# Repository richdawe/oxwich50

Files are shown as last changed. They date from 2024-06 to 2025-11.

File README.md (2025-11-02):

# Oxwich50

The Oxwich50 keyboard is a 40-50% keyboard that can be mounted in a 60% traymount case, using the GH60 mounting points.

It was inspired by the many unibody split keyboards that I saw in the [Keyboard Builders Digest newsletter](https://kbd.news/). A lot of those keyboards had 30-36 keys, which seemed like too few for me. I wondered what a 60% keyboard would be like if you removed some keys, added an arrow cluster, and split the halves a bit, for a _potentially_ more comfortable typing position.

The PCB and plate were designed and made for me by [Mechboards Ltd](https://mechboards.co.uk/) in the UK.

Please see also my [keymap](https://github.com/richdawe/qmk_firmware/blob/master/keyboards/oxwich50/keymaps/richdawe/keymap.c) and the [QMK support](https://github.com/richdawe/qmk_firmware/tree/master/keyboards/oxwich50), both in my fork of the QMK firmware.

The keyboard is named after [Oxwich](https://en.wikipedia.org/wiki/Oxwich), which is a village on the Gower, near Swansea in Wales, UK.

# TODOs

 - [ ] Licence for h/w
 - [ ] Add photos
 - [ ] List of limitations with v1
   - [ ] plate hole in wrong place, stab screw conflict with 60% case post, maybe unnecessary holes? in the plate for 60% cases I use
   - [ ] also need to clip one of the plastic legs on a switch going in the RHS enter position - this is on the RHS, row above bottom one; was this with 5-pin switches?
   - [ ] holes for stabs are quite tight, could make them wider - also would they fit more stabs if they were taller?
 - [ ] Make the PCB compatible with o-ring mounting in a Bakeneko60 case
 - [ ] Other improvements? E.g.: Expose Pico debug connector for debugging QMK with the Rasbperry Pi debug peripheral?

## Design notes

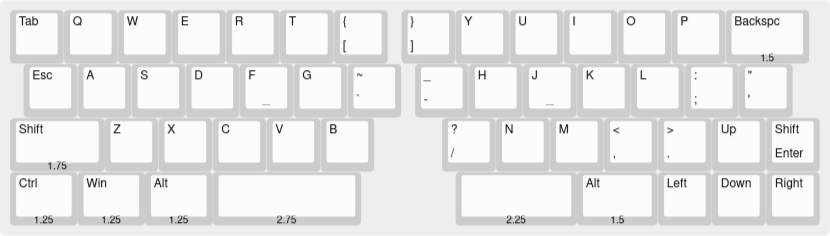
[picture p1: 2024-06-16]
oxwich50-kle.png

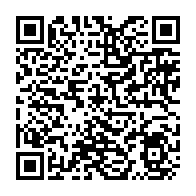
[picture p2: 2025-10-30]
qr/oxwich50-keymap-qr.png

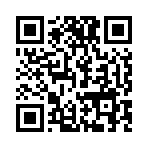
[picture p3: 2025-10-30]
qr/oxwich50-source-qr.png

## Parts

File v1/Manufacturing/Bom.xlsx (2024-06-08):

Designator | Footprint | Quantity | Value | JLCPCB Part #
SW43,SW42,SW44,SW46,SW29,SW14,SW47,SW45,SW28,SW4,SW18,SW21,SW40,SW6,SW10,SW39,SW36,SW13,SW15,SW25,SW26,SW32,SW20,SW33,SW49,SW1,SW12,SW16,SW22,SW27,SW19,SW11,SW48,SW5,SW30,SW50,SW17,SW41,SW3,SW24,SW38,SW35,SW34,SW2,SW37,SW31,SW8,SW7,SW23,SW9 | SW_Hotswap_Kailh_MX_1.00u | 50 | SW_Push_45deg | CPG151101S11
DS1 | D_SOD-123 | 1 | DSK34 SOD-123 | C41029
D7,D26,D49,D33,D17,D38,D2,D29,D31,D41,D40,D36,D11,D13,D39,D35,D24,D4,D43,D37,D45,D19,D1,D30,D48,D28,D10,D15,D32,D14,D20,D23,D18,D5,D22,D34,D8,D6,D50,D9,D16,D46,D12,D3,D21,D27,D47,D25,D44,D42 | D_SOD-123 | 50 | 1N4148W | C81598
U2 | SOIC-8_5.23x5.23mm_P1.27mm | 1 | W25Q128JVS | C97521
C14,C15,C4,C7 | C_0402_1005Metric | 4 | 1u | C52923
U3 | SOT-23-5 | 1 | TLV70030DDCR | C36463
R8,R9 | R_0402_1005Metric | 2 | 5K1 | C25905
R3,R7 | R_0402_1005Metric | 2 | 1K | C11702
C11,C9,C5,C6,C10,C12,C8,C13 | C_0402_1005Metric | 8 | 100n | C1525
U1 | QFN-56-1EP_7x7mm_P0.4mm_EP3.2x3.2mm | 1 | RP2040 | C2040
R5,R4 | R_0402_1005Metric | 2 | 27R4 | C284479
R2 | R_0402_1005Metric | 1 | 200R | C25087
RST1 | SW_SPST_TL3342 | 1 | SW_SPST_TL3342 | C2886897
C2,C3 | C_0402_1005Metric | 2 | 27pF | C86287
F1 | R_0805_2012Metric_Pad1.20x1.40mm_HandSolder | 1 | Fuse | C883108
Y1 | Crystal_SMD_2520-4Pin_2.5x2.0mm | 1 | 12Mhz, 10pf, 10ppm | C284154
C1 | C_0402_1005Metric | 1 | 2u2 | C12530
J1 | USB_C_Receptacle_HRO_TYPE-C-31-M-12 | 1 | USB_C_Receptacle_USB2.0 | C165948
R6 | R_0402_1005Metric | 1 | 10K | C25744
R1 | R_0402_1005Metric | 1 | 1R | C881121
U4 | Diodes_UDFN-10_1.0x2.5mm_P0.5mm | 1 | D3V3XA4B10LP | C1980462

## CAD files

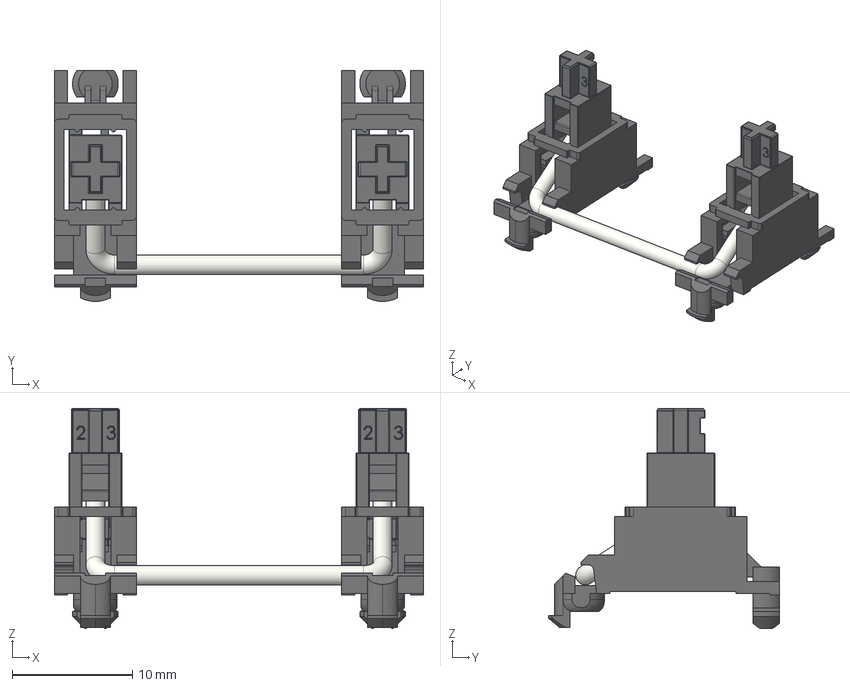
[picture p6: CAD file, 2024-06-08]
v1/kiswitch/source_3d/Mounting_Keyboard_Stabilizer/Stabilizer_Cherry_MX_2u.FCStd
30.7 x 19.2 x 18.3 mm
Bar
Stabilizer_Key_
Stabilizer_Base_
Stabilizer_Key
Stabilizer_Base

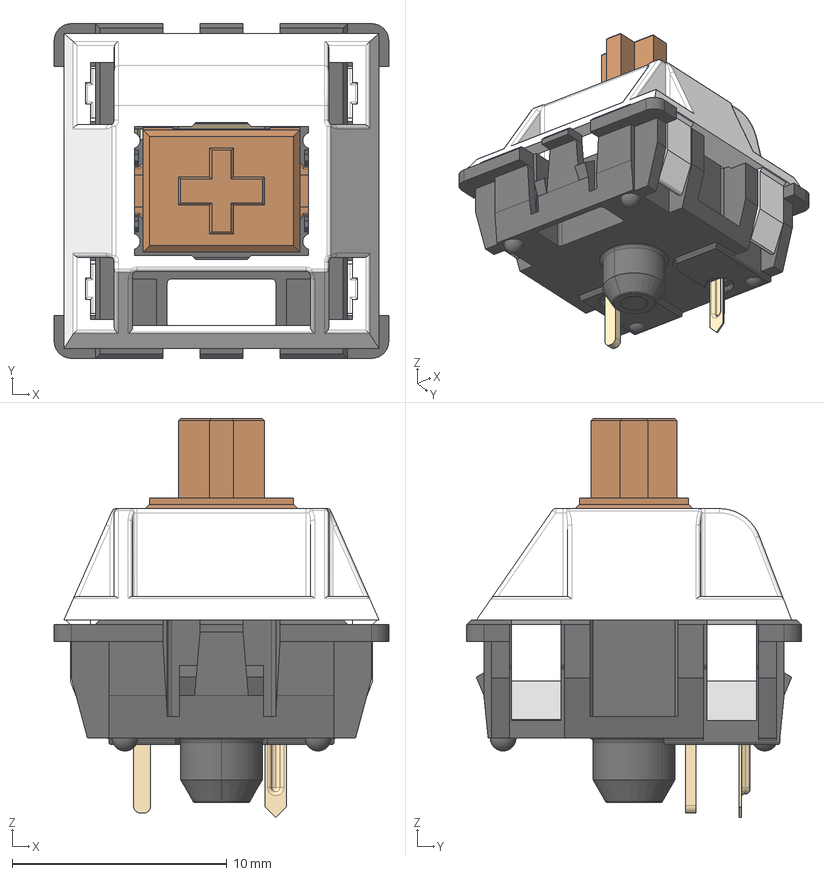
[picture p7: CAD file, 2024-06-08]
v1/kiswitch/source_3d/Switch_Keyboard_Cherry_MX/SW_Cherry_MX_Plate.FCStd
15.6 x 15.6 x 18.6 mm
Lower_Housing
Upper_Housing
Stem
Pin_1
Pin_2
Spring
Clicker

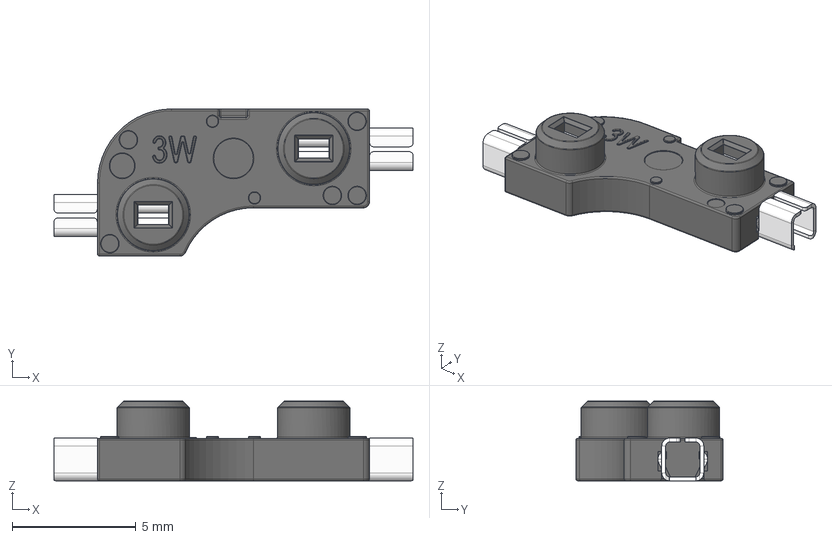
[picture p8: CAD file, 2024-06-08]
v1/kiswitch/source_3d/Switch_Keyboard_Kailh/SW_Hotswap_Kailh.FCStd
14.5 x 5.95 x 3.22 mm
Pin_1
Pin_2
Plastic

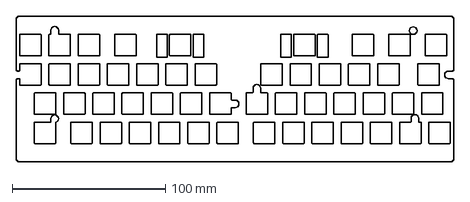
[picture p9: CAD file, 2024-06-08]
v1/Manufacturing/plate.dxf
285.3 x 94.8 mm

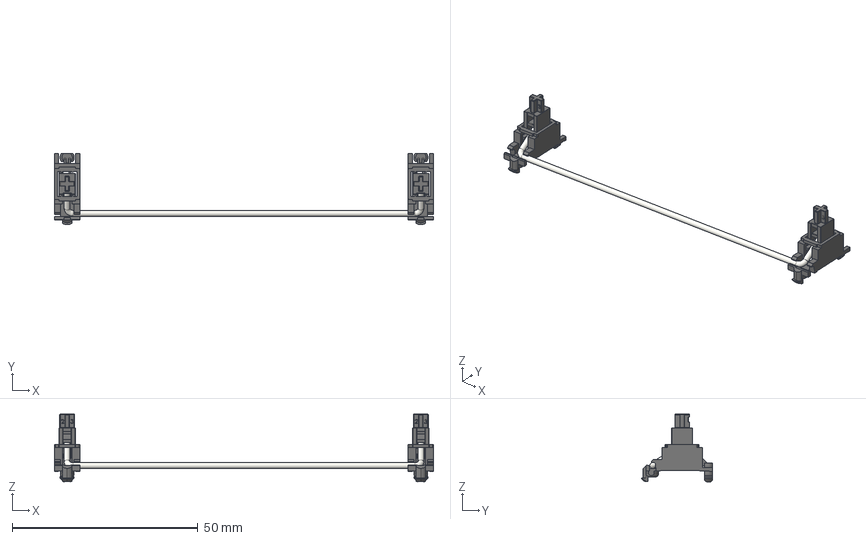
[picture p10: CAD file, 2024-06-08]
v1/kiswitch/source_3d/Mounting_Keyboard_Stabilizer/Stabilizer_Cherry_MX_6u.FCStd
102.1 x 19.2 x 18.3 mm
Bar
Stabilizer_Key_
Stabilizer_Base_
Stabilizer_Key
Stabilizer_Base

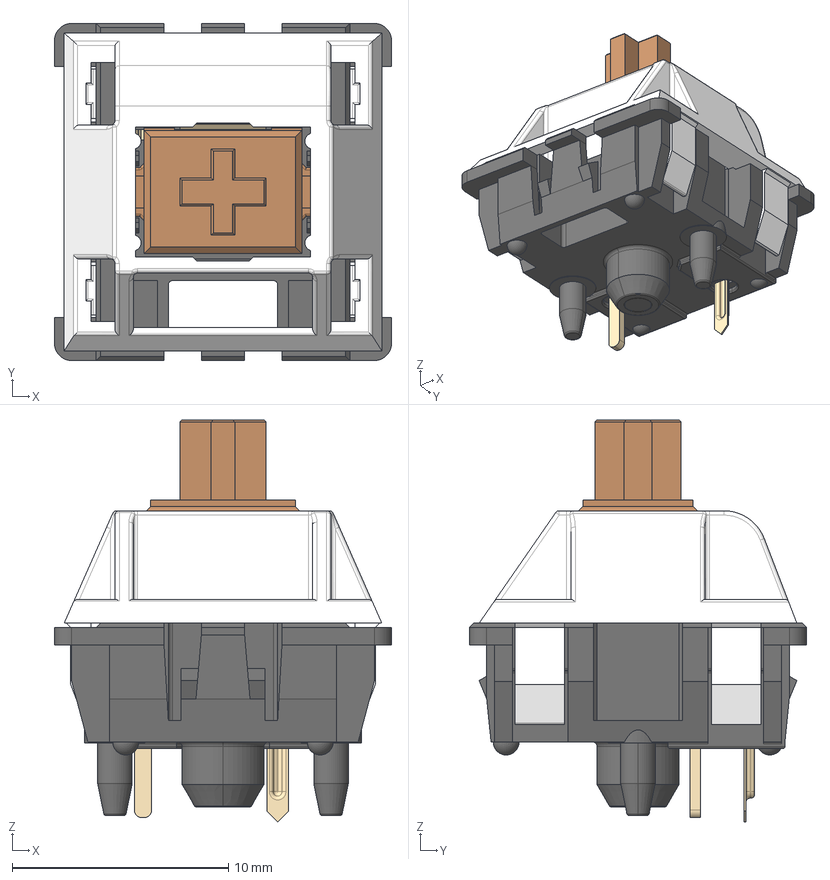
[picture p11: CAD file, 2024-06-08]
v1/kiswitch/source_3d/Switch_Keyboard_Cherry_MX/SW_Cherry_MX_PCB.FCStd
15.6 x 15.6 x 18.6 mm
Lower_Housing
Upper_Housing
Stem
Pin_1
Pin_2
Spring
Clicker

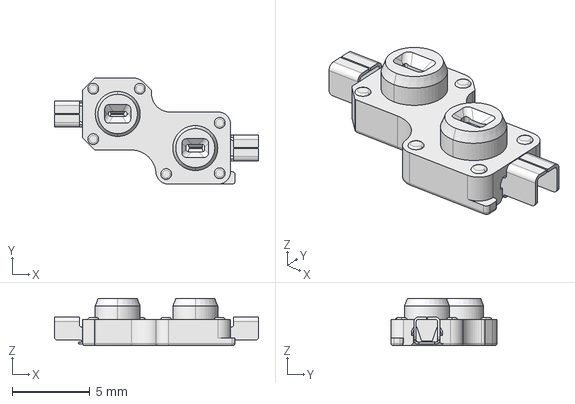
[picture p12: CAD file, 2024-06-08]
v1/kiswitch/source_3d/Switch_Keyboard_Kailh/SW_Hotswap_Kailh_Choc_v1.FCStd
13.2 x 6.85 x 3.05 mm

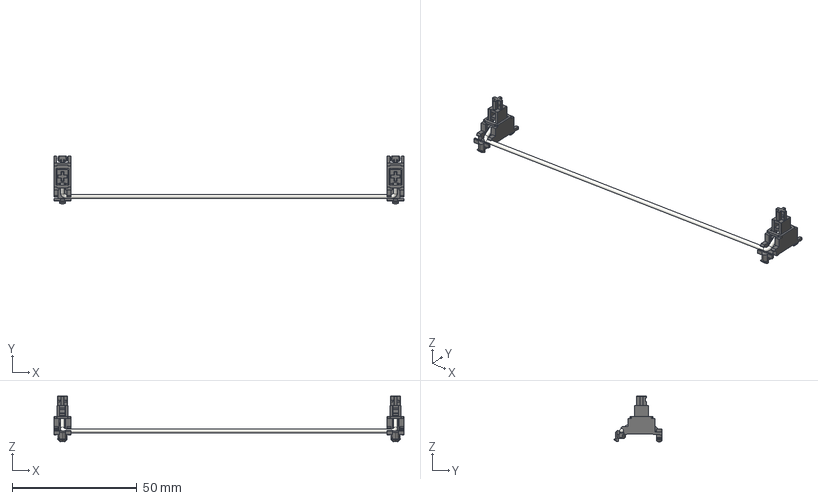
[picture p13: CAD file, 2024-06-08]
v1/kiswitch/source_3d/Mounting_Keyboard_Stabilizer/Stabilizer_Cherry_MX_8u.FCStd
140.1 x 19.2 x 18.3 mm
Bar
Stabilizer_Key_
Stabilizer_Base_
Stabilizer_Key
Stabilizer_Base

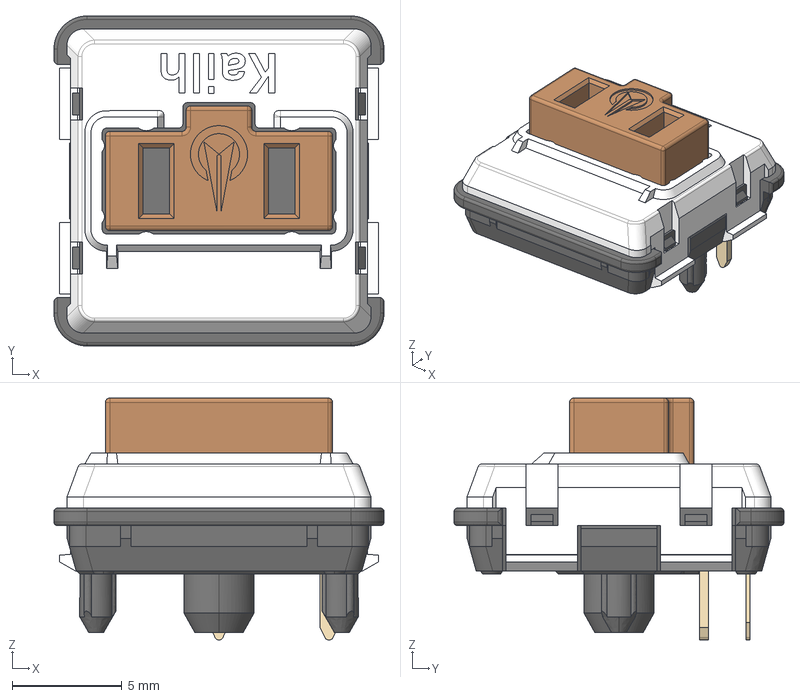
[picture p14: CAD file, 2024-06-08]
v1/kiswitch/source_3d/Switch_Keyboard_Kailh/SW_Kailh_Choc_V1.FCStd
15.0 x 15.0 x 11.0 mm
Upper_Housing
Lower_Housing
Stem
Pin_2
Pin_1

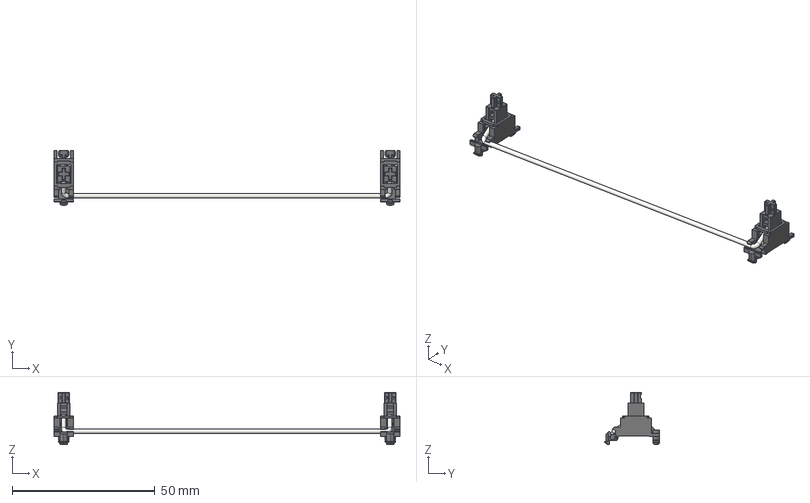
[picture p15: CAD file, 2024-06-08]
v1/kiswitch/source_3d/Mounting_Keyboard_Stabilizer/Stabilizer_Cherry_MX_7u.FCStd
121.1 x 19.2 x 18.3 mm
Bar
Stabilizer_Key_
Stabilizer_Base_
Stabilizer_Key
Stabilizer_Base

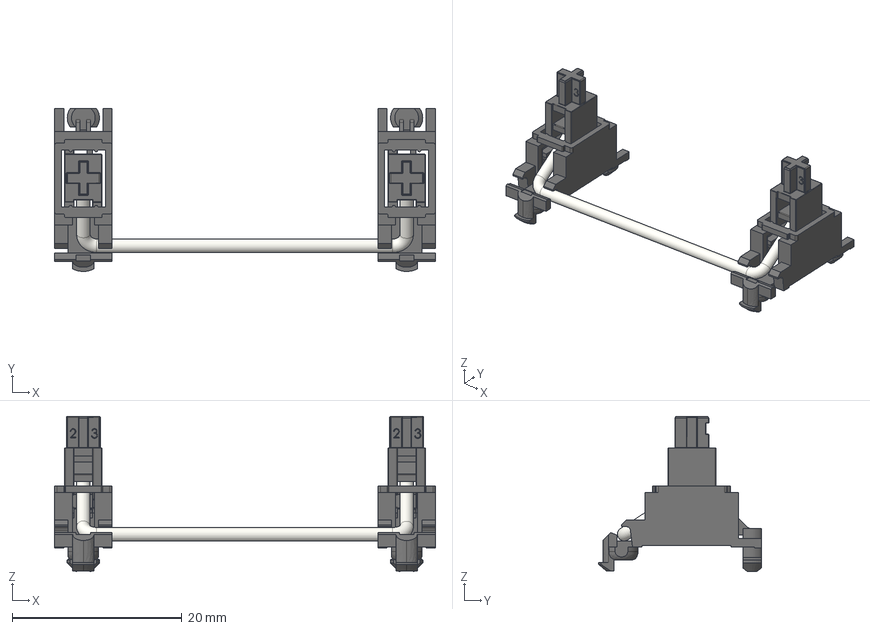
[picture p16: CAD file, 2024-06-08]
v1/kiswitch/source_3d/Mounting_Keyboard_Stabilizer/Stabilizer_Cherry_MX_3u.FCStd
44.9 x 19.2 x 18.3 mm
Bar
Stabilizer_Key_
Stabilizer_Base_
Stabilizer_Key
Stabilizer_Base

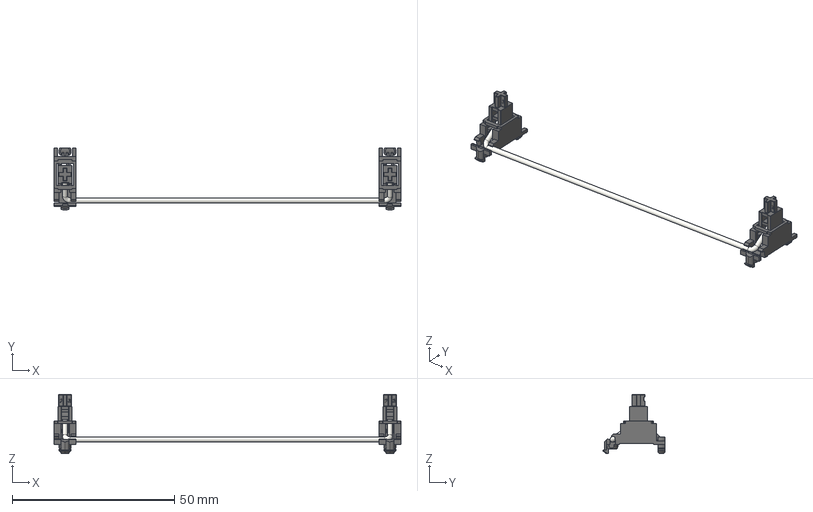
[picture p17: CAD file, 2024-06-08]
v1/kiswitch/source_3d/Mounting_Keyboard_Stabilizer/Stabilizer_Cherry_MX_6.25u.FCStd
106.8 x 19.2 x 18.3 mm
Bar
Stabilizer_Key_
Stabilizer_Base_
Stabilizer_Key
Stabilizer_Base

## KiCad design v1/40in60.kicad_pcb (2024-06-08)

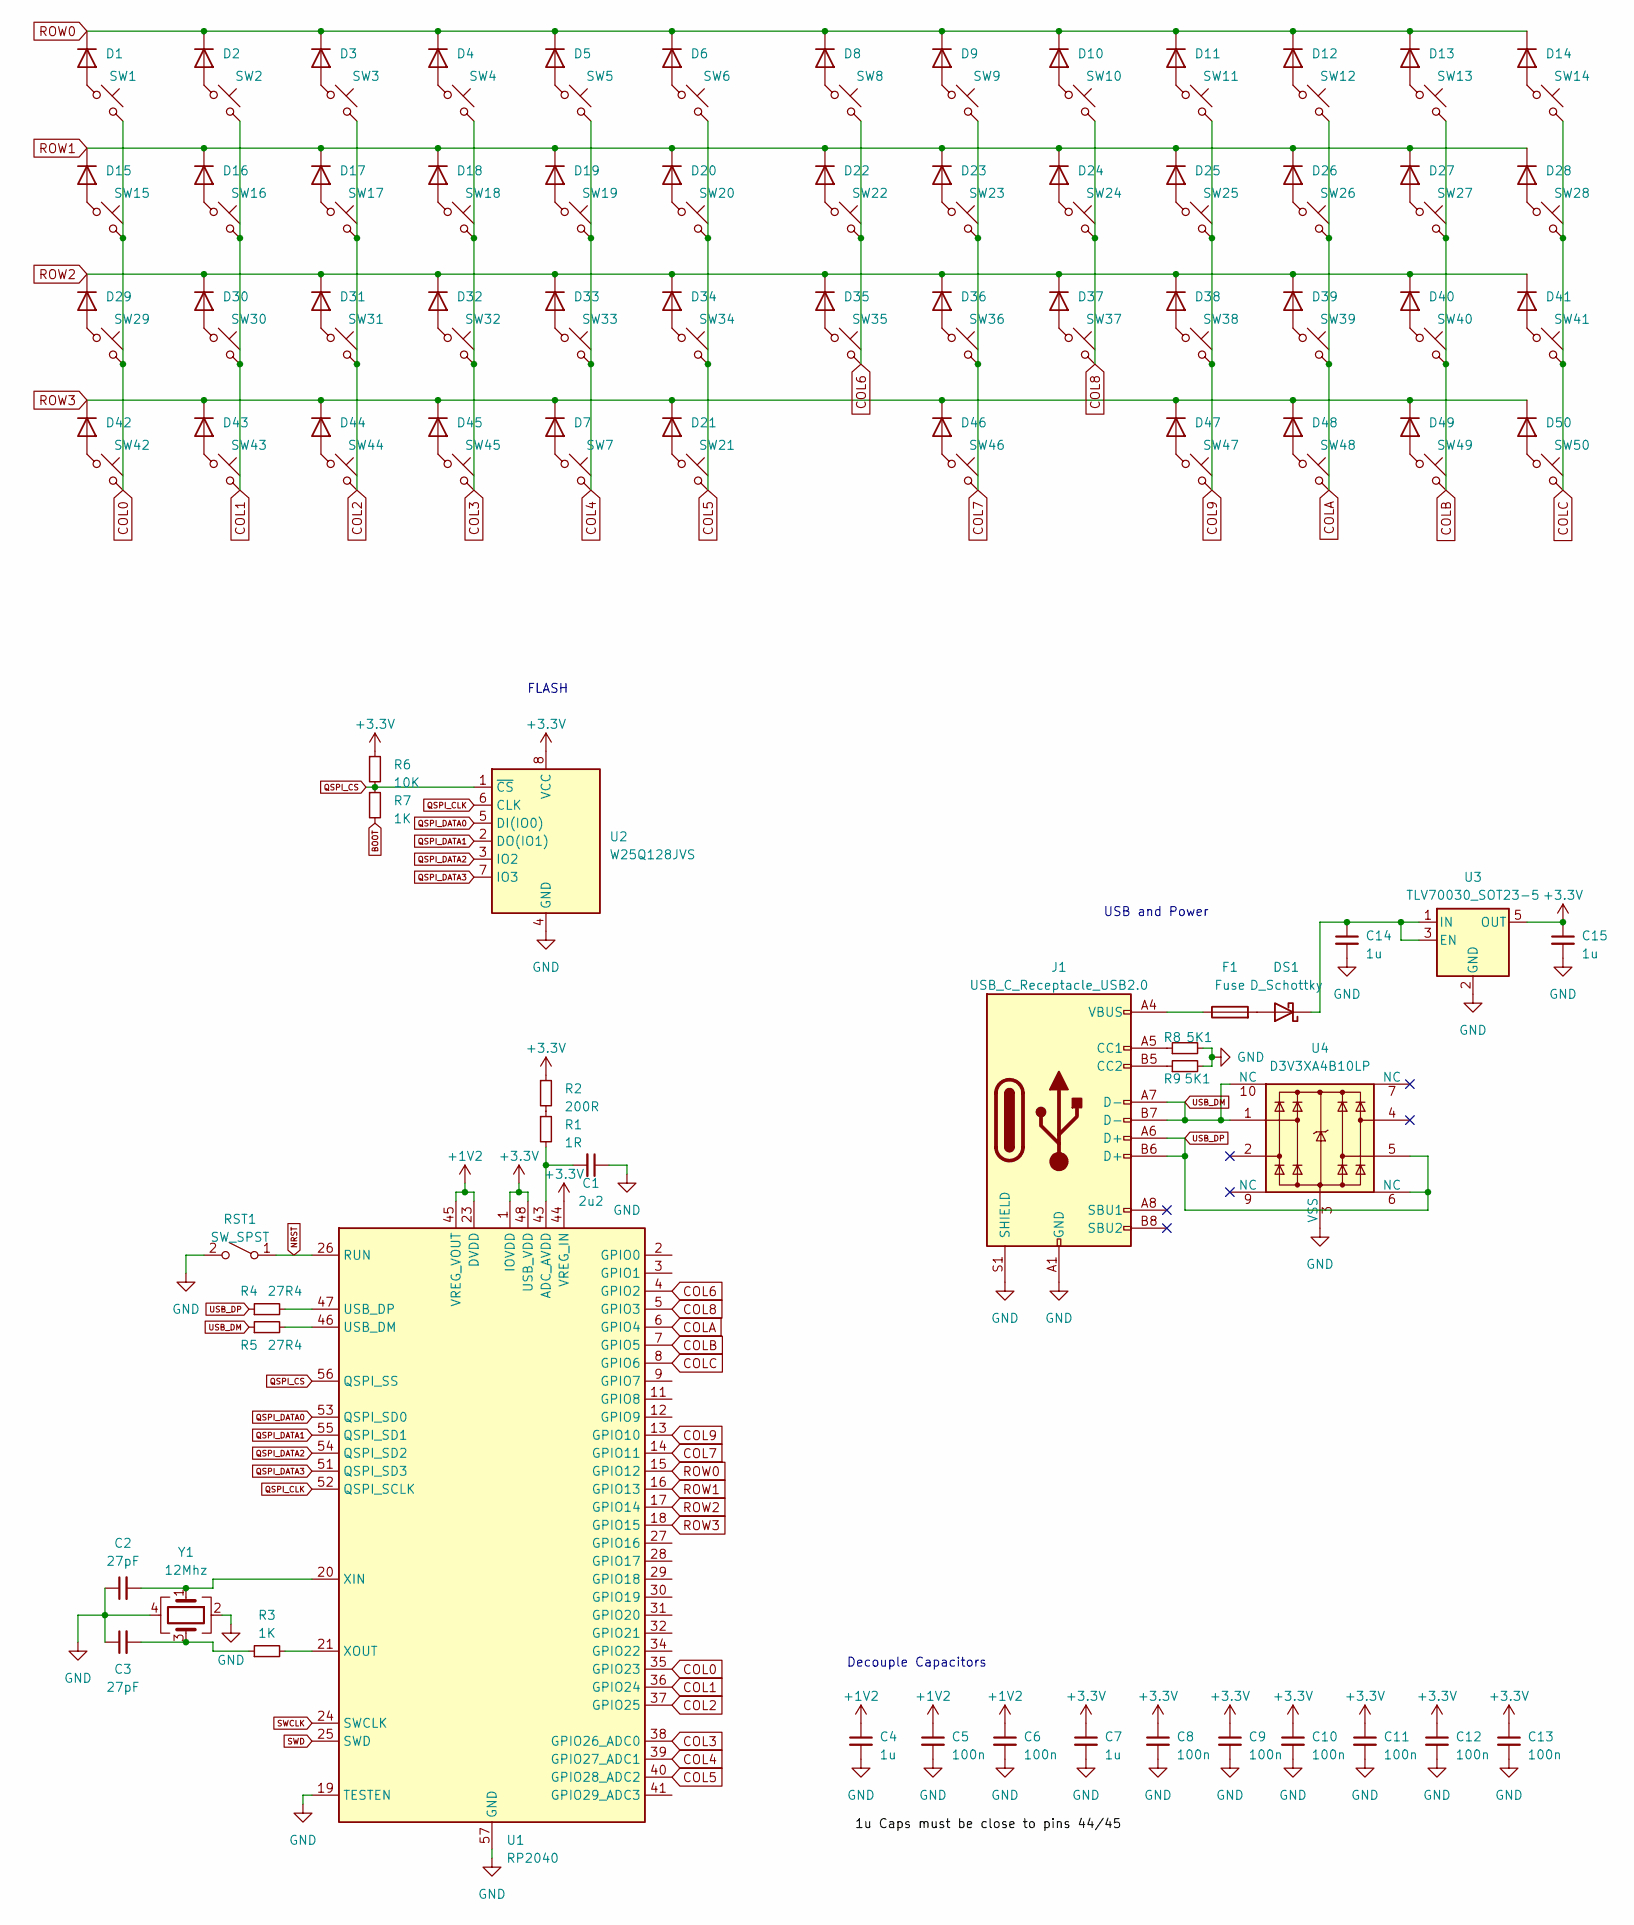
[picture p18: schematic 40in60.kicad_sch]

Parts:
C1: 2u2; C_0402_1005Metric
C2, C3: 27pF; C_0402_1005Metric
C4, C7, C14, C15: 1u; C_0402_1005Metric
C5, C6, C8, C9, C10, C11, C12, C13: 100n; C_0402_1005Metric
D1, D2, D3, D4, D5, D6, D7, D8, D9, D10, D11, D12, D13, D14, D15, D16, D17, D18, D19, D20, D21, D22, D23, D24, D25, D26, D27, D28, D29, D30, D31, D32, D33, D34, D35, D36, D37, D38, D39, D40, D41, D42, D43, D44, D45, D46, D47, D48, D49, D50: 1N4148W; D_SOD-123
DS1: D_Schottky; D_SOD-123
F1: Fuse; R_0805_2012Metric_Pad1.20x1.40mm_HandSolder
J1: USB_C_Receptacle_USB2.0; USB_C_Receptacle_HRO_TYPE-C-31-M-12
R1: 1R; R_0402_1005Metric
R2: 200R; R_0402_1005Metric
R3, R7: 1K; R_0402_1005Metric
R4, R5: 27R4; R_0402_1005Metric
R6: 10K; R_0402_1005Metric
R8, R9: 5K1; R_0402_1005Metric
RST1: SW_SPST; SW_SPST_TL3342
SW1, SW2, SW3, SW4, SW5, SW6, SW7, SW8, SW9, SW10, SW11, SW12, SW13, SW15, SW16, SW17, SW18, SW19, SW20, SW21, SW22, SW23, SW24, SW25, SW26, SW27, SW28, SW30, SW31, SW32, SW33, SW34, SW35, SW36, SW37, SW38, SW39, SW40, SW41, SW48, SW49, SW50: SW_Push_45deg; SW_Hotswap_Kailh_MX_1.00u
SW14, SW47: SW_Push_45deg; SW_Hotswap_Kailh_MX_1.50u
SW29: SW_Push_45deg; SW_Hotswap_Kailh_MX_1.75u
SW42, SW43, SW44: SW_Push_45deg; SW_Hotswap_Kailh_MX_1.25u
SW45: SW_Push_45deg; SW_Hotswap_Kailh_MX_2.75u
SW46: SW_Push_45deg; SW_Hotswap_Kailh_MX_2.25u
U1: RP2040; QFN-56-1EP_7x7mm_P0.4mm_EP3.2x3.2mm
U2: W25Q128JVS; SOIC-8_5.23x5.23mm_P1.27mm
U3: TLV70030_SOT23-5; SOT-23-5
U4: D3V3XA4B10LP; Diodes_UDFN-10_1.0x2.5mm_P0.5mm
Y1: 12Mhz; Crystal_SMD_2520-4Pin_2.5x2.0mm

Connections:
+1V2: C4.1, C5.1, C6.1, U1.23 (DVDD), U1.45 (VREG_VOUT), U1.50 (DVDD)
+3.3V: C7.1, C8.1, C9.1, C10.1, C11.1, C12.1, C13.1, C15.1, R2.1, R6.1, U1.1 (IOVDD), U1.10 (IOVDD), U1.22 (IOVDD), U1.33 (IOVDD), U1.42 (IOVDD), U1.44 (VREG_IN), U1.48 (USB_VDD), U1.49 (IOVDD), U2.8 (VCC), U3.5 (OUT)
BOOT: R7.2
COL0: SW1.2, SW15.2, SW29.2, SW42.2, U1.35 (GPIO23)
COL1: SW2.2, SW16.2, SW30.2, SW43.2, U1.36 (GPIO24)
COL2: SW3.2, SW17.2, SW31.2, SW44.2, U1.37 (GPIO25)
COL3: SW4.2, SW18.2, SW32.2, SW45.2, U1.38 (GPIO26_ADC0)
COL4: SW5.2, SW7.2, SW19.2, SW33.2, U1.39 (GPIO27_ADC1)
COL5: SW6.2, SW20.2, SW21.2, SW34.2, U1.40 (GPIO28_ADC2)
COL6: SW8.2, SW22.2, SW35.2, U1.4 (GPIO2)
COL7: SW9.2, SW23.2, SW36.2, SW46.2, U1.14 (GPIO11)
COL8: SW10.2, SW24.2, SW37.2, U1.5 (GPIO3)
COL9: SW11.2, SW25.2, SW38.2, SW47.2, U1.13 (GPIO10)
COLA: SW12.2, SW26.2, SW39.2, SW48.2, U1.6 (GPIO4)
COLB: SW13.2, SW27.2, SW40.2, SW49.2, U1.7 (GPIO5)
COLC: SW14.2, SW28.2, SW41.2, SW50.2, U1.8 (GPIO6)
GND: C1.1, C2.1, C3.1, C4.2, C5.2, C6.2, C7.2, C8.2, C9.2, C10.2, C11.2, C12.2, C13.2, C14.2, C15.2, J1.A1 (GND), J1.A12 (GND), J1.B1 (GND), J1.B12 (GND), J1.S1 (SHIELD), R8.2, R9.2, RST1.2 (B), U1.19 (TESTEN), U1.57 (GND), U2.4 (GND), U3.2 (GND), U4.3 (VSS), U4.8 (VSS), Y1.2, Y1.4
NRST: RST1.1 (A), U1.26 (RUN)
unnamed: C3.2, R3.1, Y1.3
unnamed: D1.2 (A), SW1.1
unnamed: D2.2 (A), SW2.1
unnamed: D3.2 (A), SW3.1
unnamed: D4.2 (A), SW4.1
unnamed: D5.2 (A), SW5.1
unnamed: D6.2 (A), SW6.1
unnamed: D7.2 (A), SW7.1
unnamed: D8.2 (A), SW8.1
unnamed: D9.2 (A), SW9.1
unnamed: D10.2 (A), SW10.1
unnamed: D11.2 (A), SW11.1
unnamed: D12.2 (A), SW12.1
unnamed: D13.2 (A), SW13.1
unnamed: D14.2 (A), SW14.1
unnamed: D15.2 (A), SW15.1
unnamed: D16.2 (A), SW16.1
unnamed: D17.2 (A), SW17.1
unnamed: D18.2 (A), SW18.1
unnamed: D19.2 (A), SW19.1
unnamed: D20.2 (A), SW20.1
unnamed: D21.2 (A), SW21.1
unnamed: D22.2 (A), SW22.1
unnamed: D23.2 (A), SW23.1
unnamed: D24.2 (A), SW24.1
unnamed: D25.2 (A), SW25.1
unnamed: D26.2 (A), SW26.1
unnamed: D27.2 (A), SW27.1
unnamed: D28.2 (A), SW28.1
unnamed: D29.2 (A), SW29.1
unnamed: D30.2 (A), SW30.1
unnamed: D31.2 (A), SW31.1
unnamed: D32.2 (A), SW32.1
unnamed: D33.2 (A), SW33.1
unnamed: D34.2 (A), SW34.1
unnamed: D35.2 (A), SW35.1
unnamed: D36.2 (A), SW36.1
unnamed: D37.2 (A), SW37.1
unnamed: D38.2 (A), SW38.1
unnamed: D39.2 (A), SW39.1
unnamed: D40.2 (A), SW40.1
unnamed: D41.2 (A), SW41.1
unnamed: D42.2 (A), SW42.1
unnamed: D43.2 (A), SW43.1
unnamed: D44.2 (A), SW44.1
unnamed: D45.2 (A), SW45.1
unnamed: D46.2 (A), SW46.1
unnamed: D47.2 (A), SW47.1
unnamed: D48.2 (A), SW48.1
unnamed: D49.2 (A), SW49.1
unnamed: D50.2 (A), SW50.1
unnamed: DS1.2 (A), F1.2
unnamed: C14.1, DS1.1 (K), U3.1 (IN), U3.3 (EN)
unnamed: F1.1, J1.A4 (VBUS), J1.A9 (VBUS), J1.B4 (VBUS), J1.B9 (VBUS)
unnamed: J1.A5 (CC1), R8.1
unnamed: J1.B5 (CC2), R9.1
unnamed: R1.1, R2.2
unnamed: C1.2, R1.2, U1.43 (ADC_AVDD)
unnamed: R5.2, U1.46 (USB_DM)
unnamed: R4.2, U1.47 (USB_DP)
unnamed: C2.2, U1.20 (XIN), Y1.1
unnamed: R3.2, U1.21 (XOUT)
QSPI_CLK: U1.52 (QSPI_SCLK), U2.6 (CLK)
QSPI_CS: R6.2, R7.1, U1.56 (QSPI_SS), U2.1 (~CS)
QSPI_DATA0: U1.53 (QSPI_SD0), U2.5 (DI(IO0))
QSPI_DATA1: U1.55 (QSPI_SD1), U2.2 (DO(IO1))
QSPI_DATA2: U1.54 (QSPI_SD2), U2.3 (IO2)
QSPI_DATA3: U1.51 (QSPI_SD3), U2.7 (IO3)
ROW0: D1.1 (K), D2.1 (K), D3.1 (K), D4.1 (K), D5.1 (K), D6.1 (K), D8.1 (K), D9.1 (K), D10.1 (K), D11.1 (K), D12.1 (K), D13.1 (K), D14.1 (K), U1.15 (GPIO12)
ROW1: D15.1 (K), D16.1 (K), D17.1 (K), D18.1 (K), D19.1 (K), D20.1 (K), D22.1 (K), D23.1 (K), D24.1 (K), D25.1 (K), D26.1 (K), D27.1 (K), D28.1 (K), U1.16 (GPIO13)
ROW2: D29.1 (K), D30.1 (K), D31.1 (K), D32.1 (K), D33.1 (K), D34.1 (K), D35.1 (K), D36.1 (K), D37.1 (K), D38.1 (K), D39.1 (K), D40.1 (K), D41.1 (K), U1.17 (GPIO14)
ROW3: D7.1 (K), D21.1 (K), D42.1 (K), D43.1 (K), D44.1 (K), D45.1 (K), D46.1 (K), D47.1 (K), D48.1 (K), D49.1 (K), D50.1 (K), U1.18 (GPIO15)
SWCLK: U1.24 (SWCLK)
SWD: U1.25 (SWD)
USB_DM: J1.A7 (D-), J1.B7 (D-), R5.1, U4.1, U4.10 (NC)
USB_DP: J1.A6 (D+), J1.B6 (D+), R4.1, U4.5, U4.6 (NC)

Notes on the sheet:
Decouple Capacitors
USB and Power
FLASH

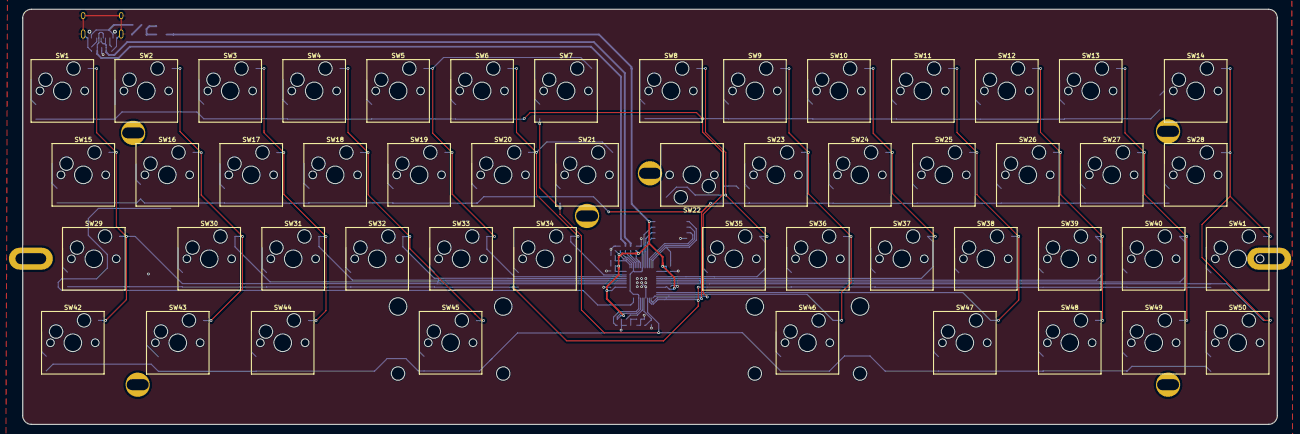
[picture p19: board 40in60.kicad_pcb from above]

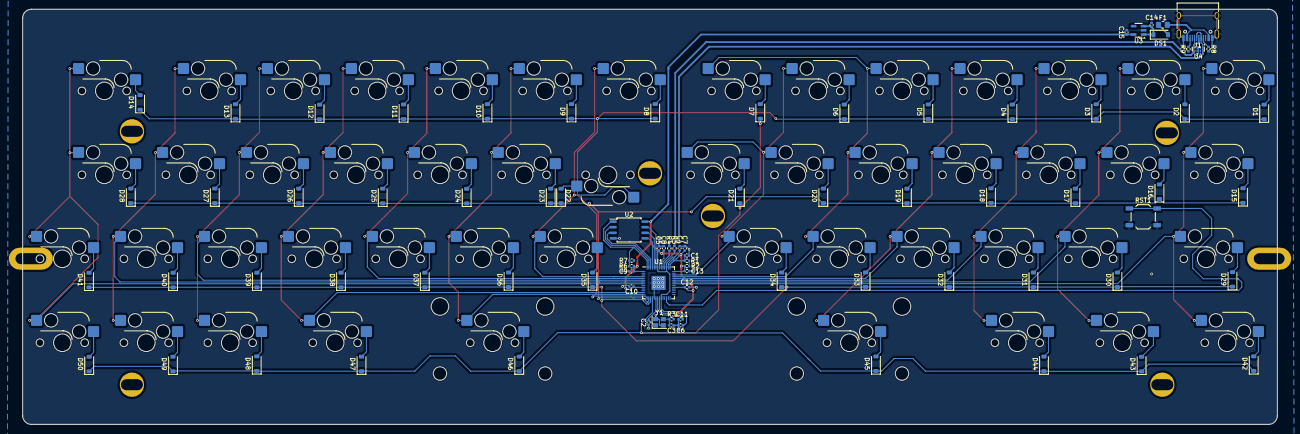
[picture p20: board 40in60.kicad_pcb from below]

Board: 2 copper layers, 284.7 x 94.2 mm, 133 parts (83 on the bottom side), 91 nets.

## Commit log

2024-06-08 Import PCB and plate design by Mechboards
    [40in60-B_Cu.gbr, 40in60-B_Mask.gbr, 40in60-B_Paste.gbr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]
2025-11-02 Stabilser holes are also a bit tight

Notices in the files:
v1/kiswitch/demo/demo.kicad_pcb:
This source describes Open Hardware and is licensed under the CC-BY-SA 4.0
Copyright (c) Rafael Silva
